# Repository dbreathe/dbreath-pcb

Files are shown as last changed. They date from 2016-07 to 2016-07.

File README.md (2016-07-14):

# dbreath-pcb

Created in EagleCad by Skip Xtian.

Program using a CP210x USB to Serial convertor.
The square on the silk screen around a pin denotes GND Pins.

To put the ESP8266 into Flash mode you must hold the "Flash" button down
before powering the unit/connecting to USB.

The 5 pin header near the GAS sensor allows you to connect the LED/OLED
break out board.

Verion 1 is very basic.
DHT 22 = Pin 13
GAS = ADC
You can also use the flash button on Pin 0

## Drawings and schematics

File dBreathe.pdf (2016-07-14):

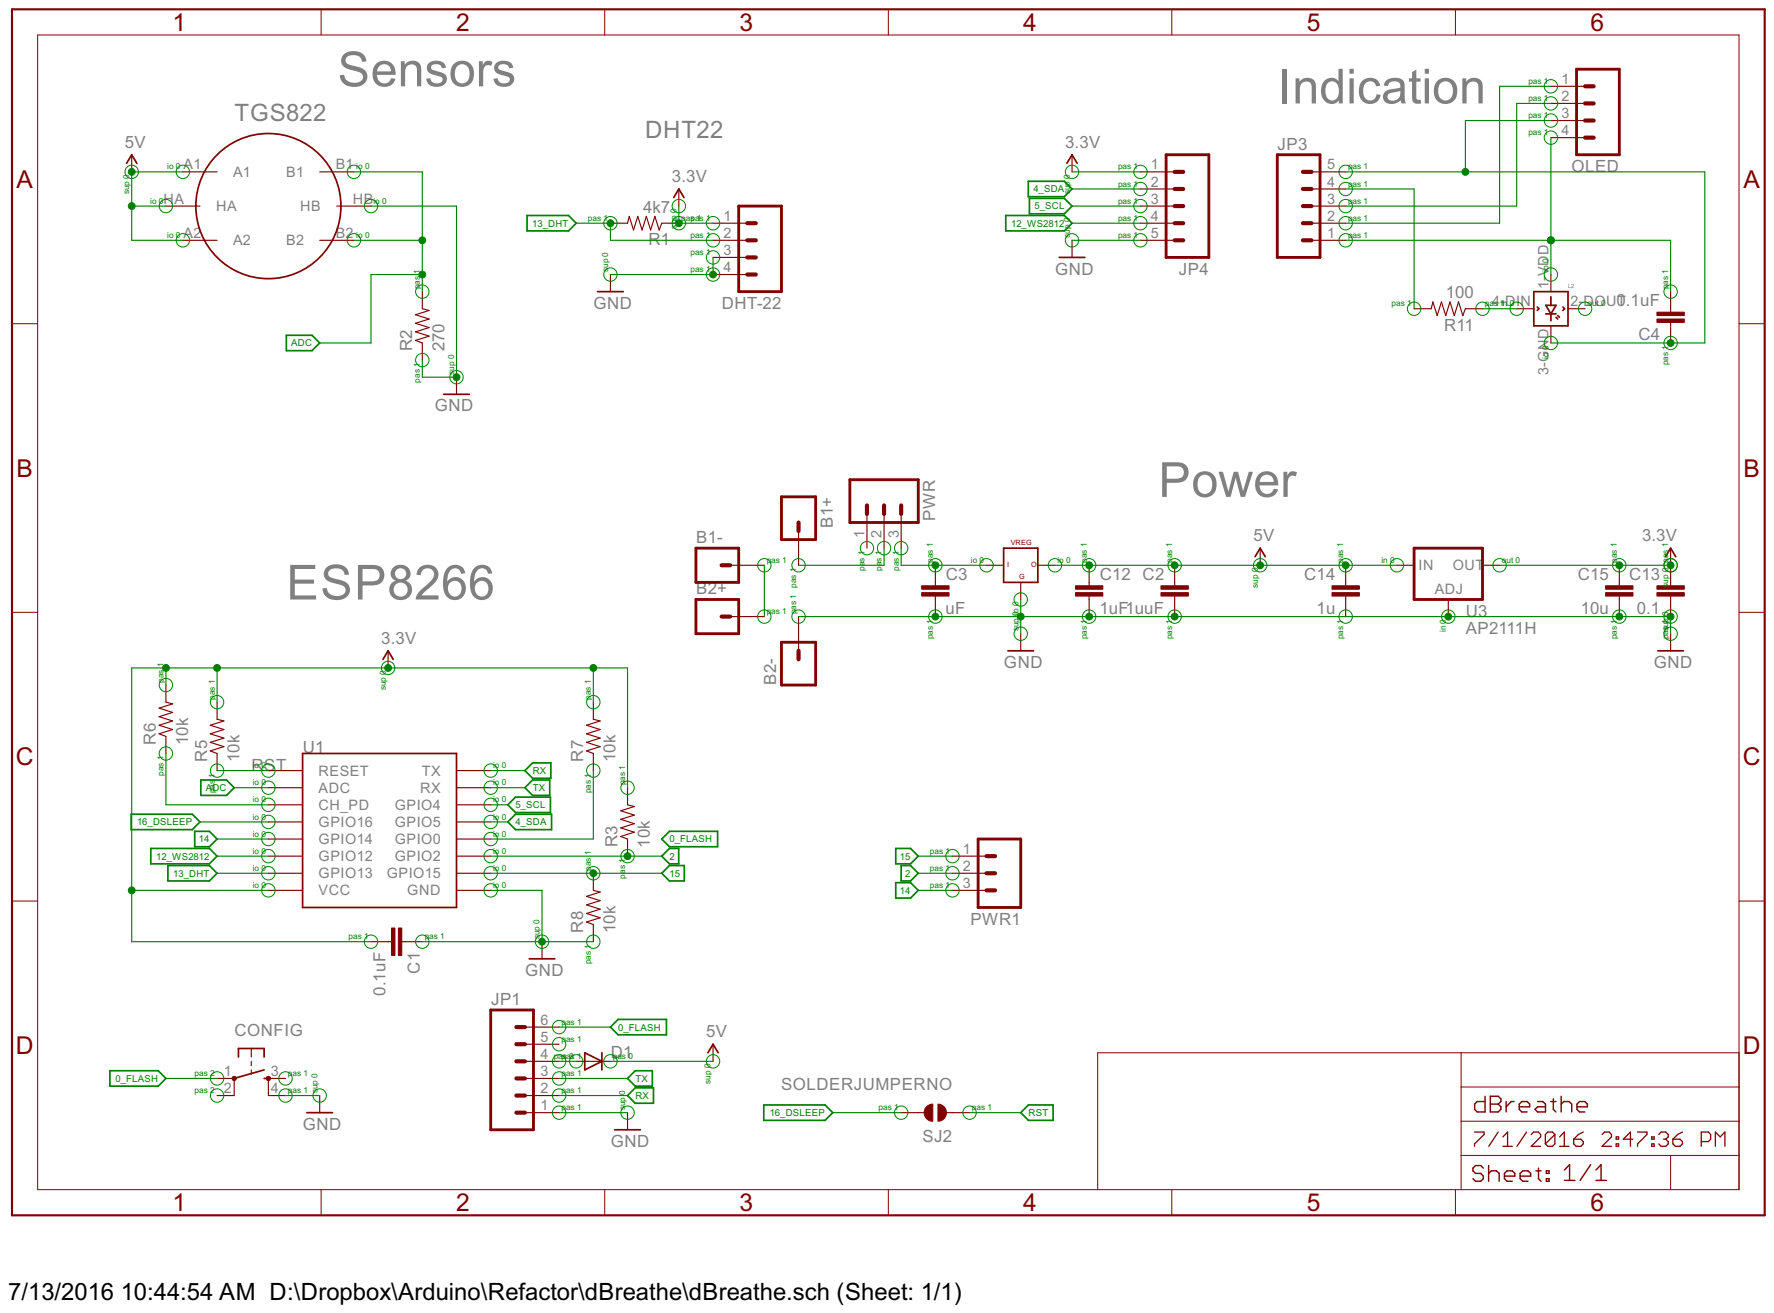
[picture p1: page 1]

pas 1 pas 1

7/13/2016 10:44:54 AM D:\Dropbox\Arduino\Refactor\dBreathe\dBreathe.sch (Sheet: 1/1)

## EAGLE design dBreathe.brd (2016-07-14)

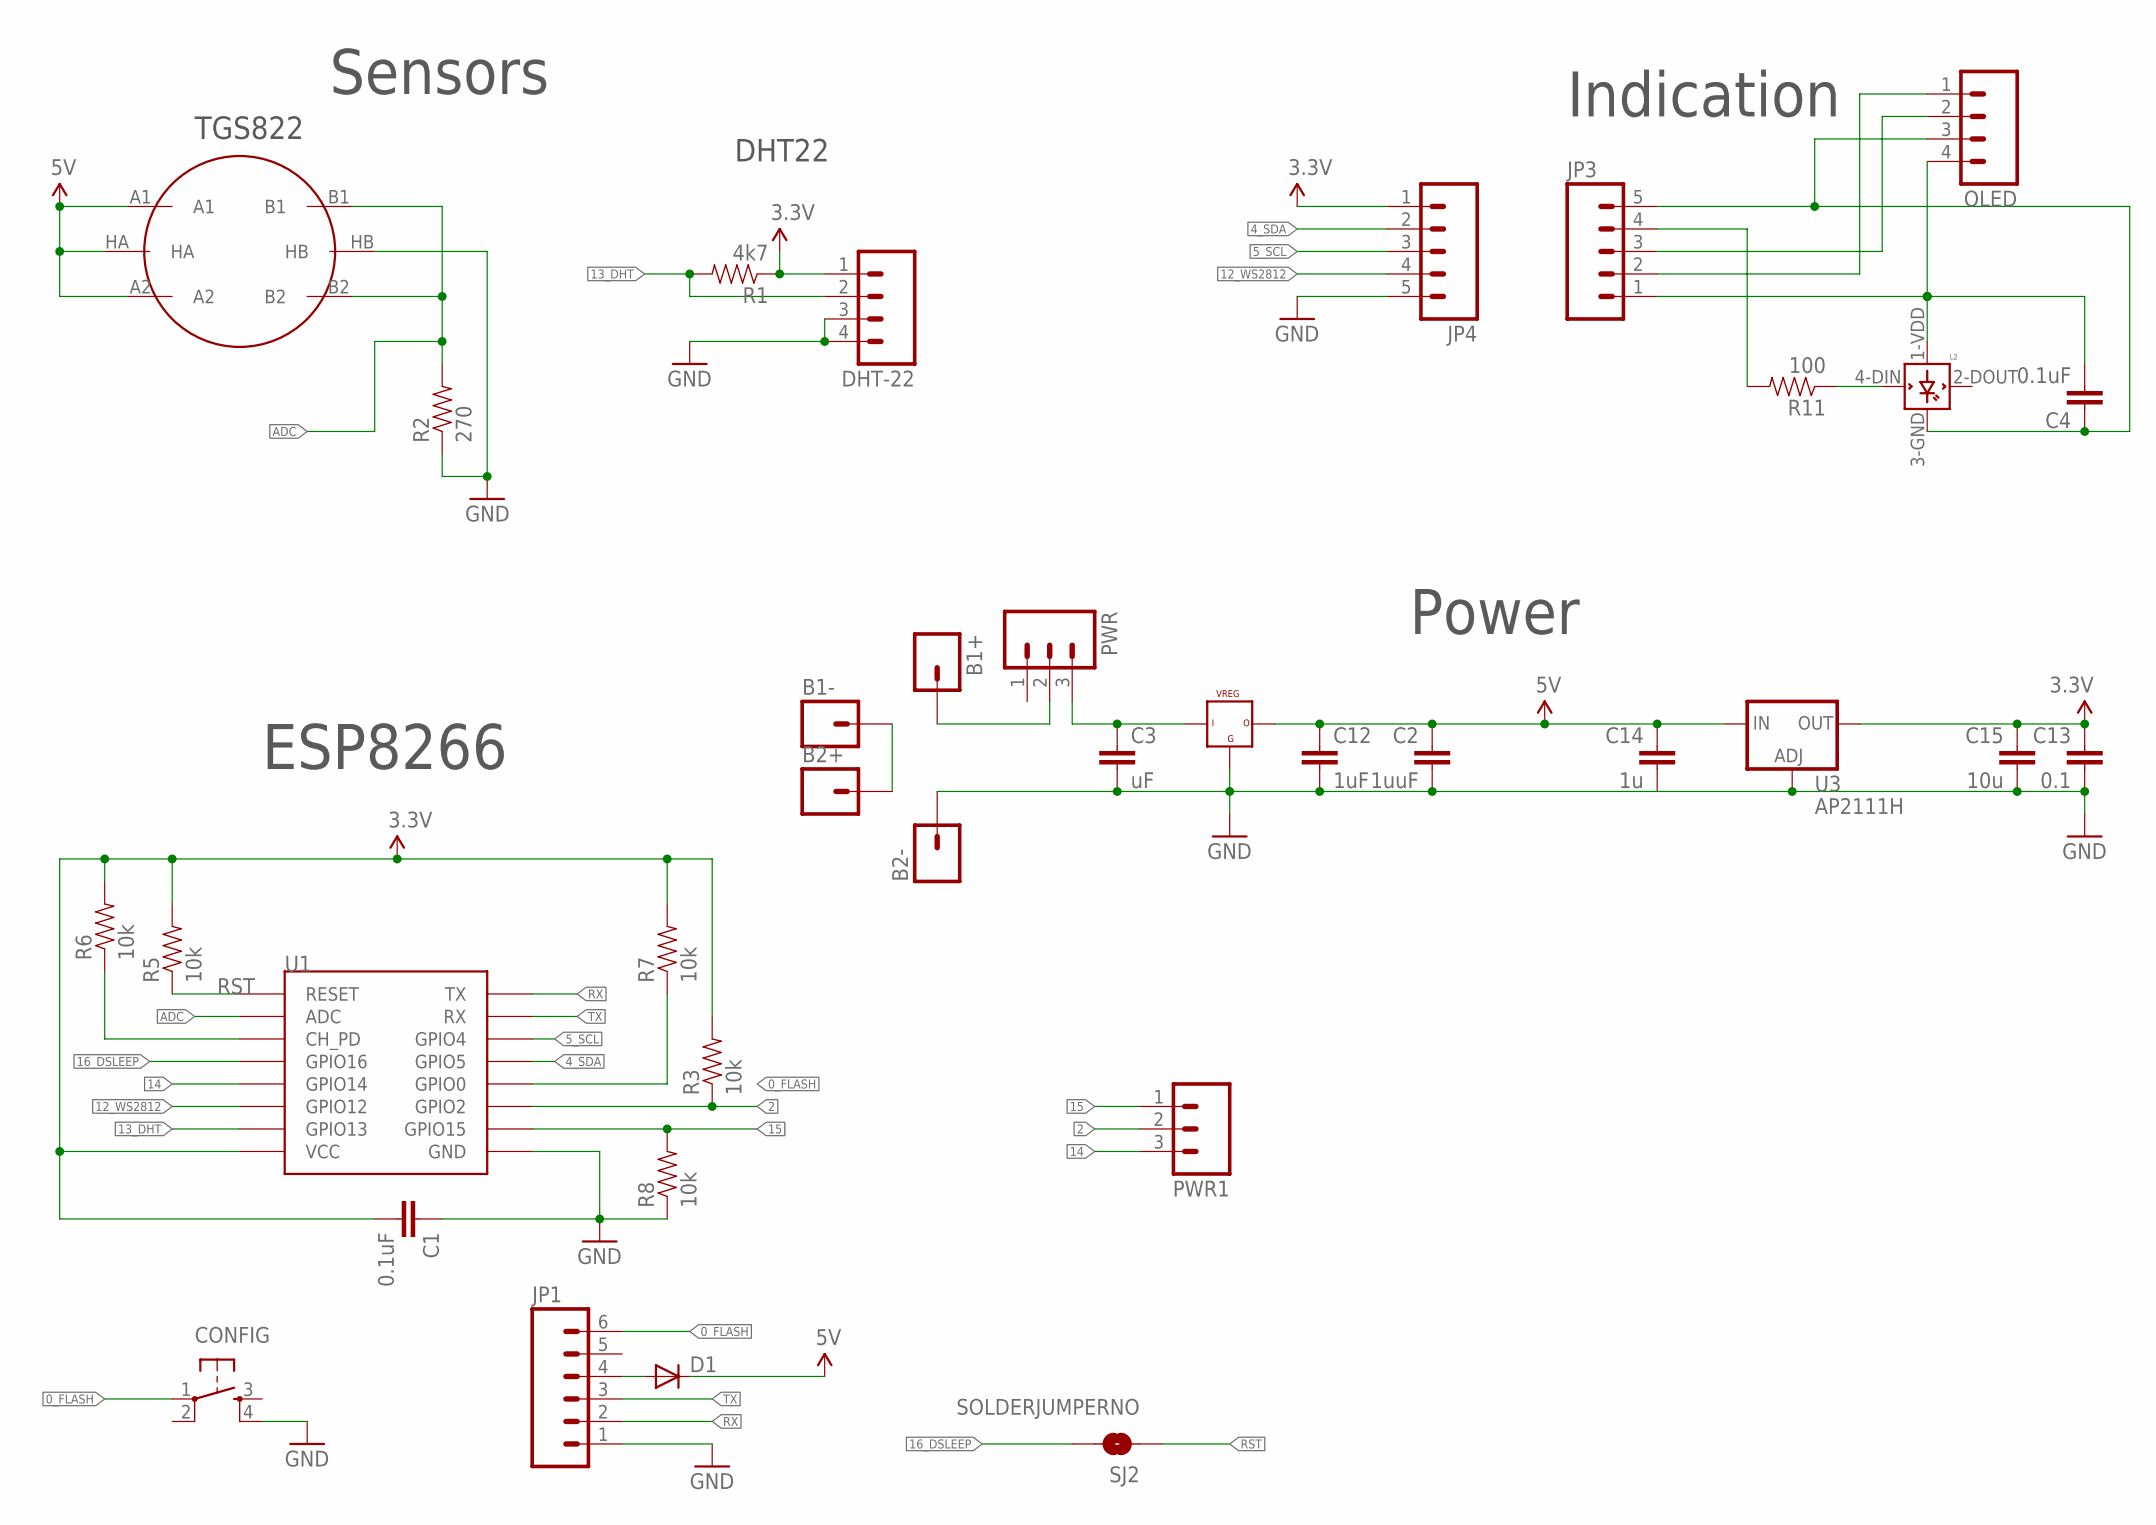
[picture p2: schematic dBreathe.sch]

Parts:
B1+, B1-, B2+, B2-: M01PTH; 1X01
C1, C4: 0.1uF; 0805
C2: 1uuF; 0805
C3: uF; 0805
C12: 1uF; 0805
C13: 0.1; 0805
C14: 1u; 0805
C15: 10u; 0805-CAP
CONFIG: TAC_SWITCHSMD; TACTILE_SWITCH_SMD
D1: DIODESOD; SOD-323
DHT-22: M04PTH; 1X04
JP1: M06NO_SILK_FEMALE_PTH; 1X06_NO_SILK
JP3, JP4: M05PTH; 1X05
L2: WS2812B
OLED: M041X04_NO_SILK; 1X04_NO_SILK
PWR, PWR1: M03PTH; 1X03
R1: 4k7; 0805
R2: 270; 0805
R3, R5, R6, R7, R8: 10k; 0805
R11: 100; 0805
SJ2: SOLDERJUMPERNO; SJ_2S-NO
U1: ESP12SMD; ESP12-SMD
U3: AP2111H; SOT223
U$4: VREG_5V; DPACK
U$7: METHANE_SENSOR; MQ-3

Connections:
0_FLASH: CONFIG.1, JP1.6, R7.1, U1.GPIO0
2: PWR1.2, R3.1, U1.GPIO2
3.3V: C1.2, C13.1, C15.1, DHT-22.1, JP4.1, R1.1, R3.2, R5.2, R6.2, R7.2, U1.VCC, U3.2 (OUT)
3V3_1: C4.2, JP3.1, L2.1-VDD (VDD), OLED.4
4_SDA: JP4.2, U1.GPIO5
4_SDA_1: JP3.2, OLED.1
5V: C2.1, C12.1, C14.1, D1.1 (C), U3.3 (IN), U$4.3, U$7.A1, U$7.A2, U$7.HA
5_SCL: JP4.3, U1.GPIO4
5_SCL_1: JP3.3, OLED.2
12_WS2812: JP4.4, U1.GPIO12
12_WS2812_1: JP3.4, R11.2
13_DHT: DHT-22.2, R1.2, U1.GPIO13
14: PWR1.3, U1.GPIO14
15: PWR1.1, R8.2, U1.GPIO15
16_DSLEEP: SJ2.2, U1.GPIO16
ADC: R2.2, U1.ADC, U$7.B1, U$7.B2
CH_PD: R6.1, U1.CH_PD
GND: B2-.1, C1.1, C2.2, C3.2, C12.2, C13.2, C14.2, C15.2, CONFIG.4, DHT-22.3, DHT-22.4, JP1.1, JP4.5, R2.1, R8.1, U1.GND, U3.1 (ADJ), U$4.2, U$7.HB
GND_1: C4.1, JP3.5, L2.3-GND (GND), OLED.3
unnamed: D1.2 (A), JP1.4
unnamed: B1+.1, PWR.2
unnamed: L2.4-DIN (DIN), R11.1
unnamed: B1-.1, B2+.1
RST: R5.1, SJ2.1, U1.RESET
RX: JP1.2, U1.TXD0 (TX)
TX: JP1.3, U1.RXD0 (RX)
VCC: C3.1, PWR.3, U$4.1

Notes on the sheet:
DHT22
Indication
Sensors
Power
ESP8266
TGS822

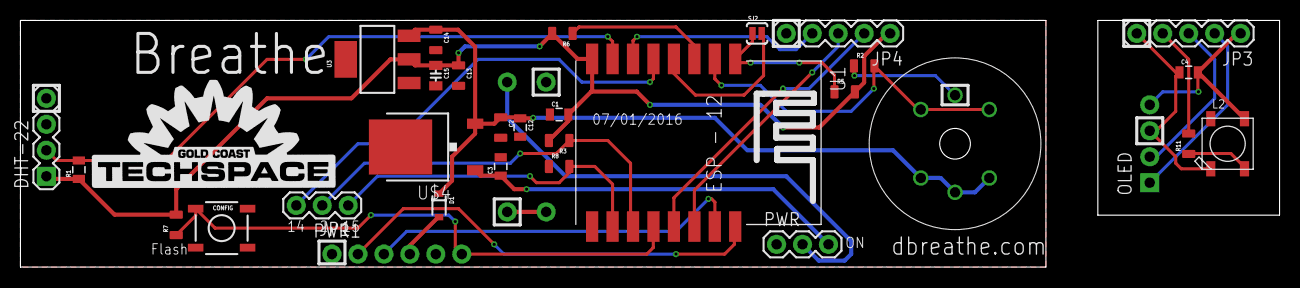
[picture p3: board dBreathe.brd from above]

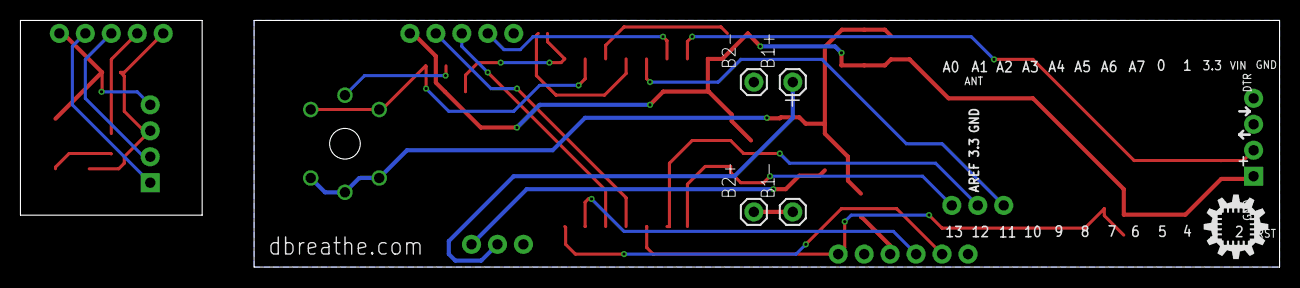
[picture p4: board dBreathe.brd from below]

Board: 2 copper layers, 100.3 x 24.1 mm, 37 parts (5 on the bottom side), 27 nets.

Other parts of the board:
U$1: GCTS_X0.5_TSILK
U$15: ID_LOGO_X0.25

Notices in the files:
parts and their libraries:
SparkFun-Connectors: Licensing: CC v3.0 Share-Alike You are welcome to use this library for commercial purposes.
